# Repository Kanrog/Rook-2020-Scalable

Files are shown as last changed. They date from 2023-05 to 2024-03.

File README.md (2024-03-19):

<h1> Rook 2020 Scalable</h1>

<p>This is my mod for the Rook 2020 to make it fully scalable to any size.<br />
<h4>STLs are not updated here anymore, only on printables.</h4>
<h3><a href="https://www.printables.com/model/482283-rook-2020-scalable-mk1" rel="ugc" target="_blank">Check this out on printables </a></h3>
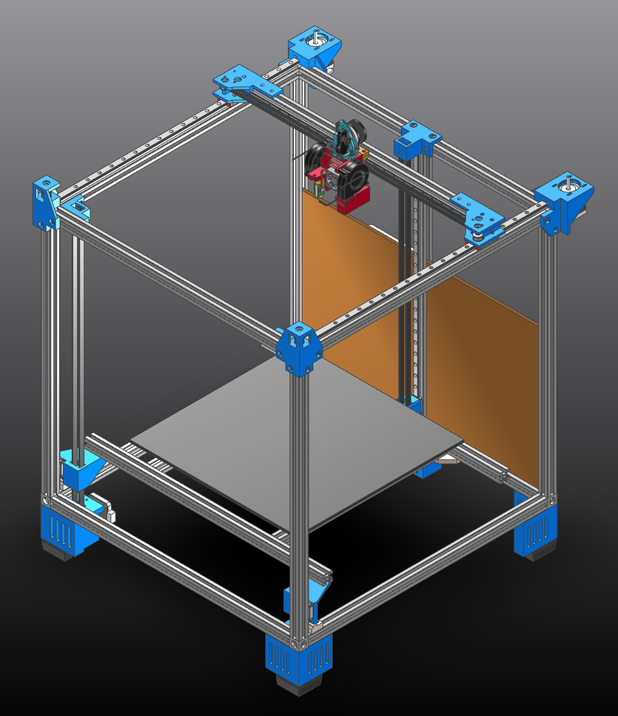
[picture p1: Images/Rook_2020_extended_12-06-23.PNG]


<p>This also adds a tripple belted Z-axis<br />
<br />
Uses the same BOM as the ROOK 2020, but with some additional hardware.<br />
<em>(Full BOM will be made when it is built and tested)</em></p>

(please note, the diagonal step is not updated, it was only made for the bed-section)

<p><br />
<em><strong>To determine your extrusion and rail lenghts, add 150mm to your bed-size and 100mm to your desired Z-height</strong></em><br />
<br />
For a 200x200x200 build volume, your extrusions would be 350x350 for top and bottom frame and 300 for Z.<br />
<br />
<em><strong>X-axis extrusion and rail is 50mm shorter than your top frame.</strong></em><br />
<br />
<p>Bed is made up of 2x extrusions the same length as your top frame and 2x the same as your top-frame - 150mm.<p/>
<br />
Supports MGN9C for the Z axis and X axis, and MGN12C for Y-axis.<br />
In theory, the X axis can use any rail to adapt to your desired printhead.<br />
<br />
Here is a calculator by Icesythe7 and MartinBspheroid to help you find your sizes!<br />

<h3><a href="https://kanrog.github.io/Rook-2020-Scalable-Calculator/" rel="ugc" target="_blank">Rook Scalable Calculator </a></h3>

<br />
Want to use the parts from your Ender-3? have a look at <a href="https://www.printables.com/model/487388-rook-e3" rel="ugc" target="_blank">THIS</a></p>

<a href="https://docs.google.com/spreadsheets/d/1HToAhn2cysvaPQEpnX_CcEi542RhAoKbjcgvA1xYTR8/edit?usp=sharing" rel="ugc" target="_blank">Rough BOM (WIP)</a></p>

<h4><br />
<em>Want to help me beta-test this? let me know!</em></h4>



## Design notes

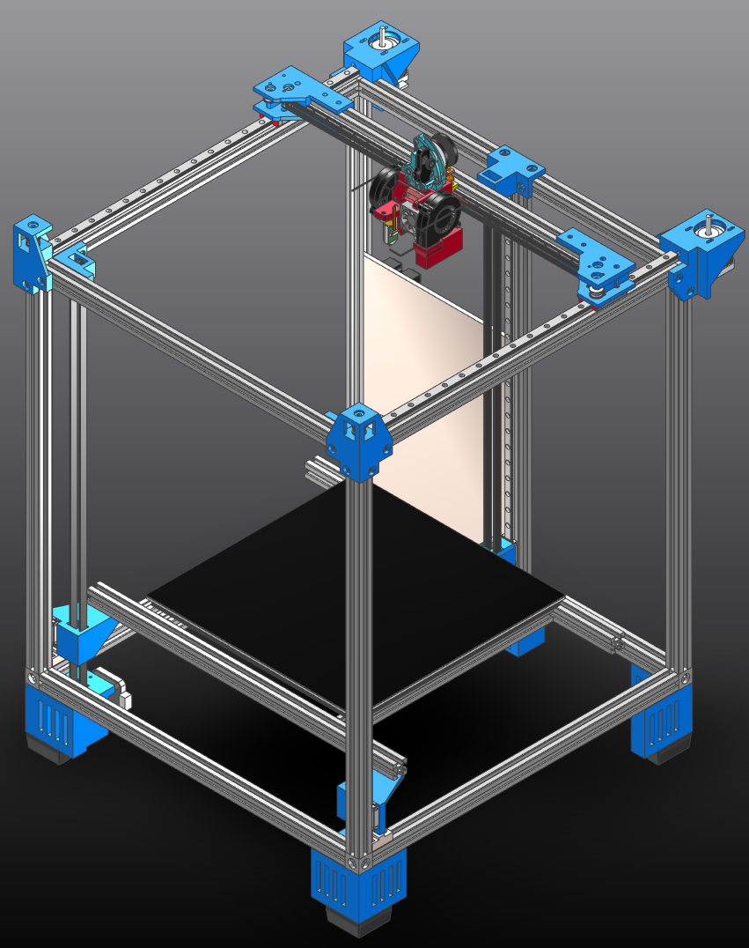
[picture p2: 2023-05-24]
Images/Rook_2020_extended.PNG

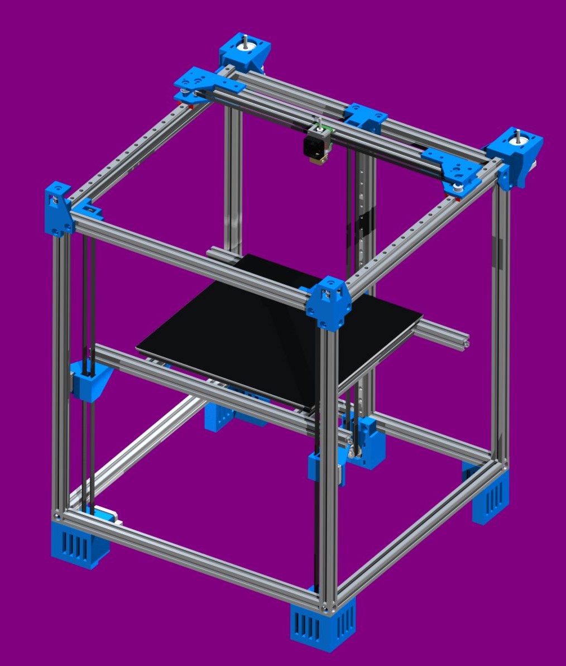
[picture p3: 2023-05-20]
Images/ICRender_crop.jpg

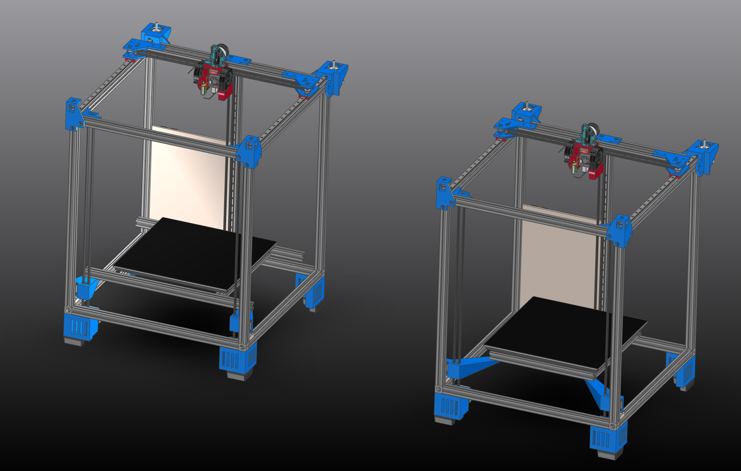
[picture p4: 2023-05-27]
Images/Rook_2020_extended_diagonal.PNG

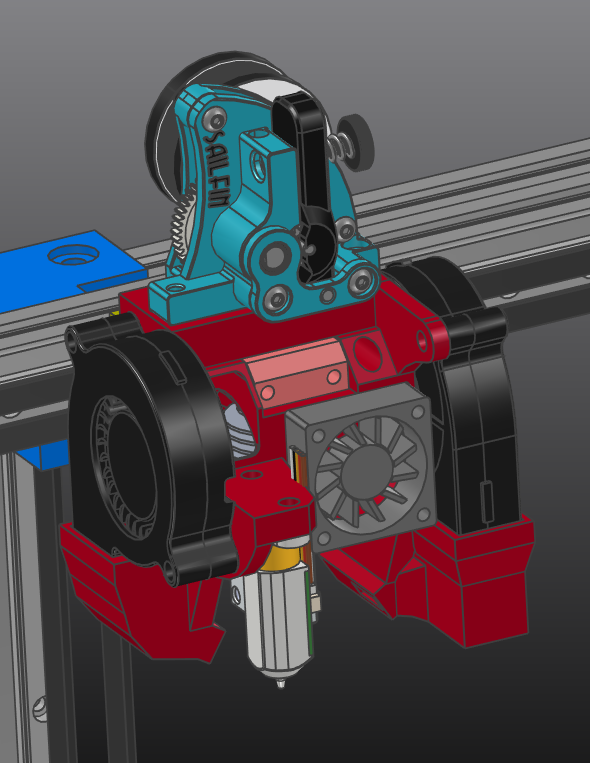
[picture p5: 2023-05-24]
Images/Brick_v0.PNG

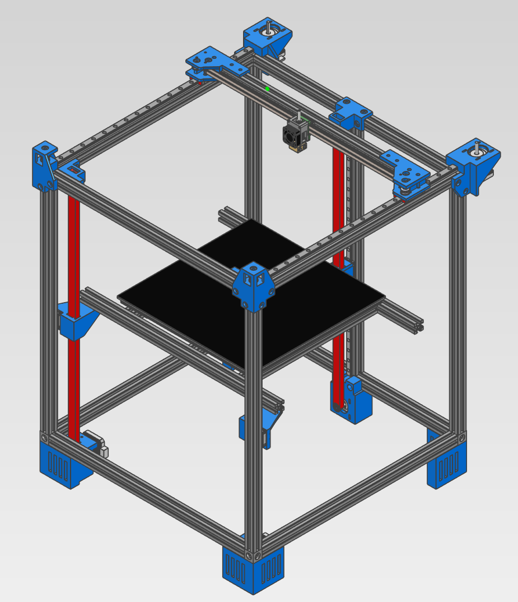
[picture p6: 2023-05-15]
Images/rook2020scalable.PNG

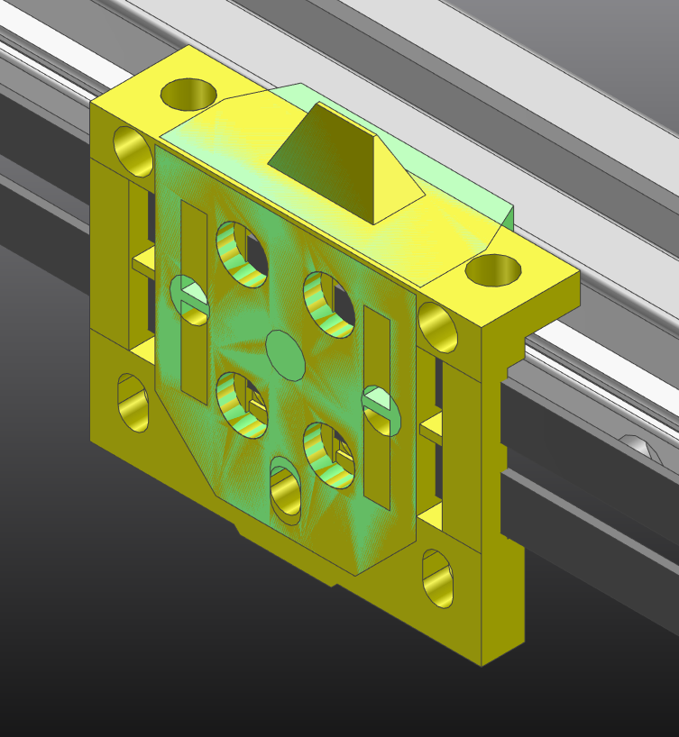
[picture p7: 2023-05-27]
Images/Brick_v0_plate_origin.PNG

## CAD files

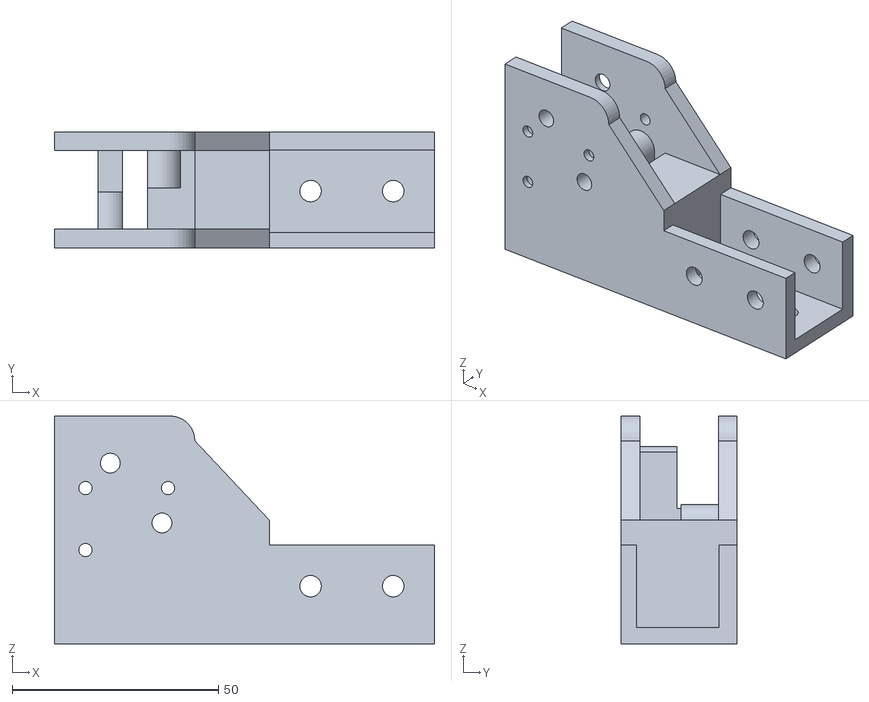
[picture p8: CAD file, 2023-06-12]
STL/1x_Y_Carriage Left_MGN12C.stl
92.0 x 28.1 x 55.2

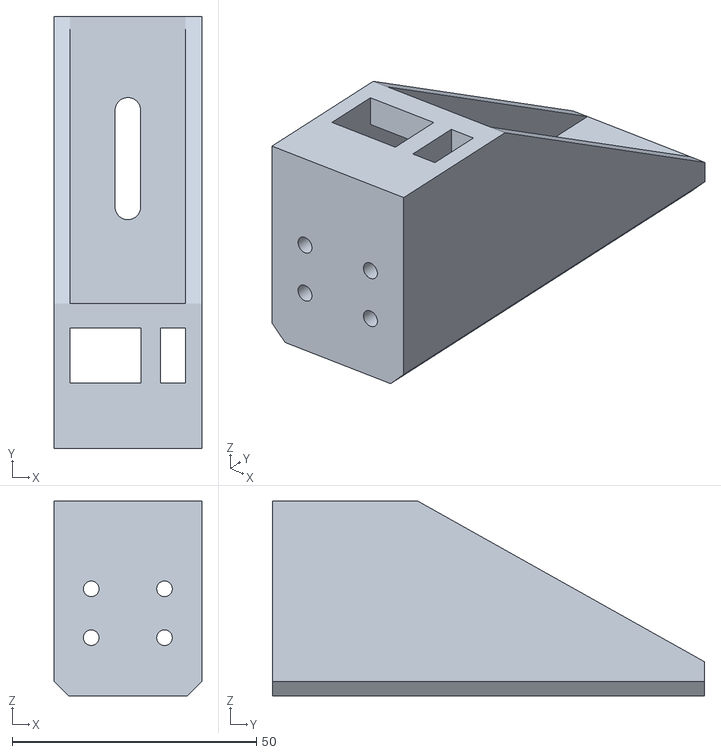
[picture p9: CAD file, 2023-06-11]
STL/1x_Z Carriage Rear_V2.stl
30.2 x 88.4 x 39.9

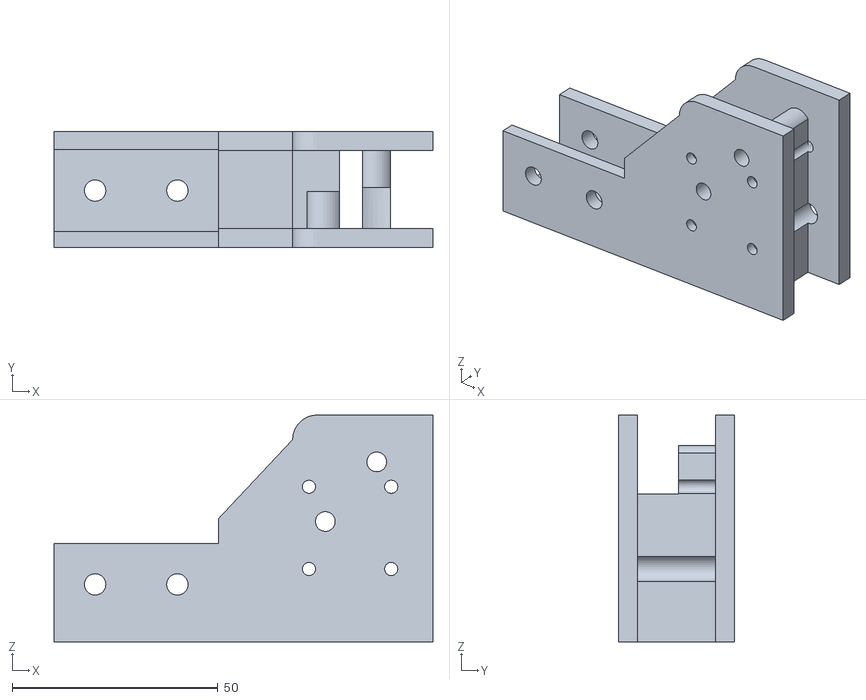
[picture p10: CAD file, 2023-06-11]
STL/1x_Y_Carriage Right_MGN12H.stl
92.2 x 28.1 x 55.2

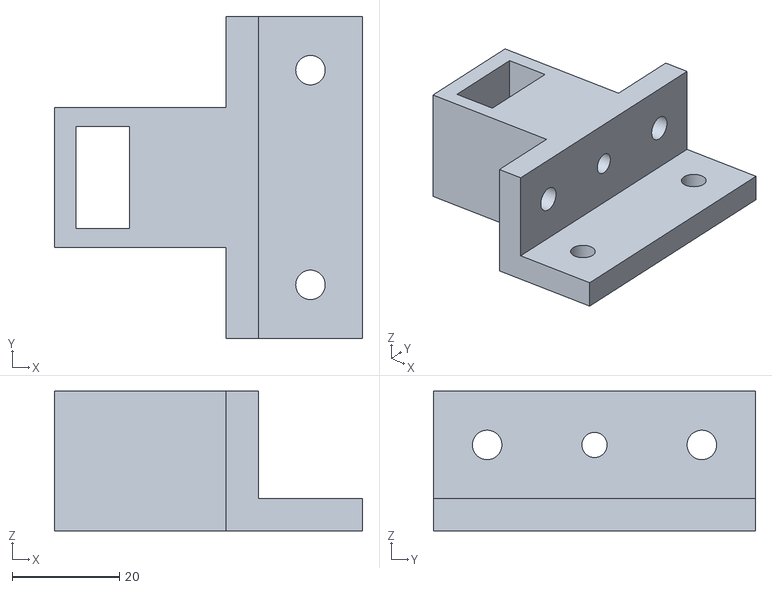
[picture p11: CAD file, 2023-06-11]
STL/1x_Z-Idler Rear.stl
57.4 x 60.0 x 26.0

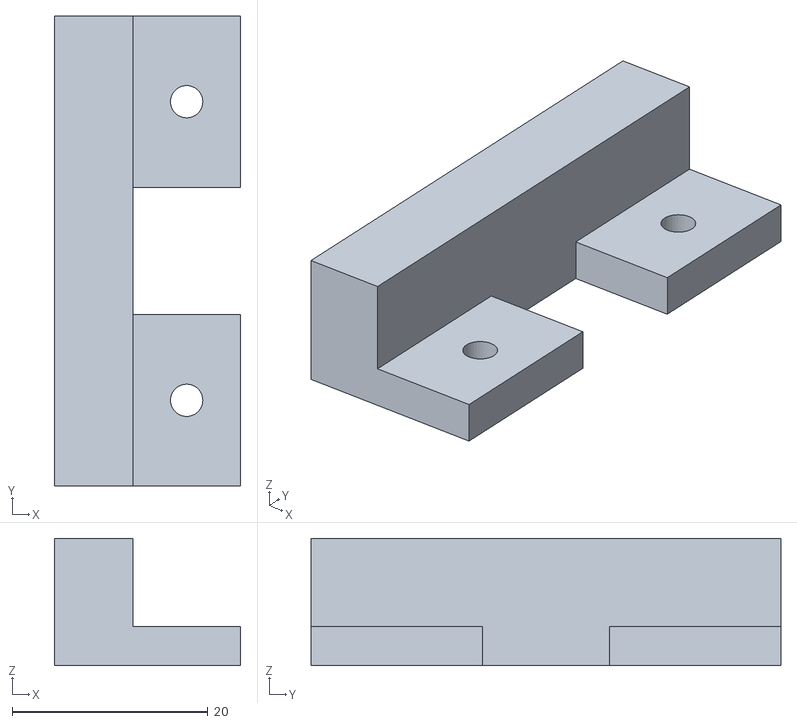
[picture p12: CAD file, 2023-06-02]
STL/1x_TPU-dampener rear.stl
19.0 x 48.0 x 13.0

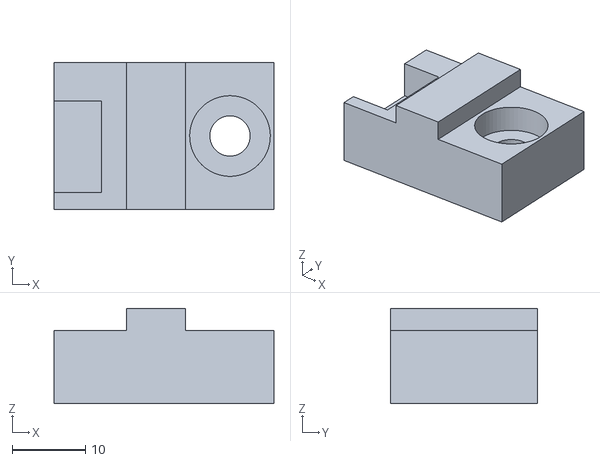
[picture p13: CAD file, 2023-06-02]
STL/2x_TPU-dampener front.stl
30.0 x 20.0 x 13.0

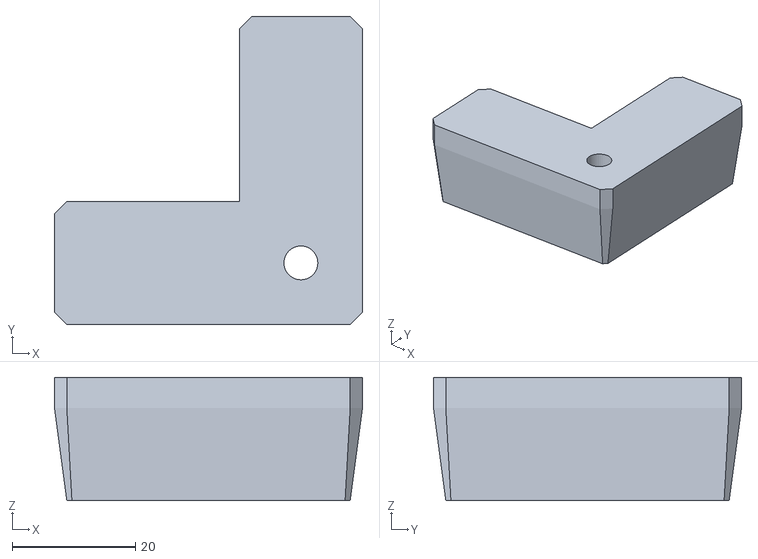
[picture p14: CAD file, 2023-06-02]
STL/4x_ TPU-feet.stl
50.0 x 50.0 x 20.0

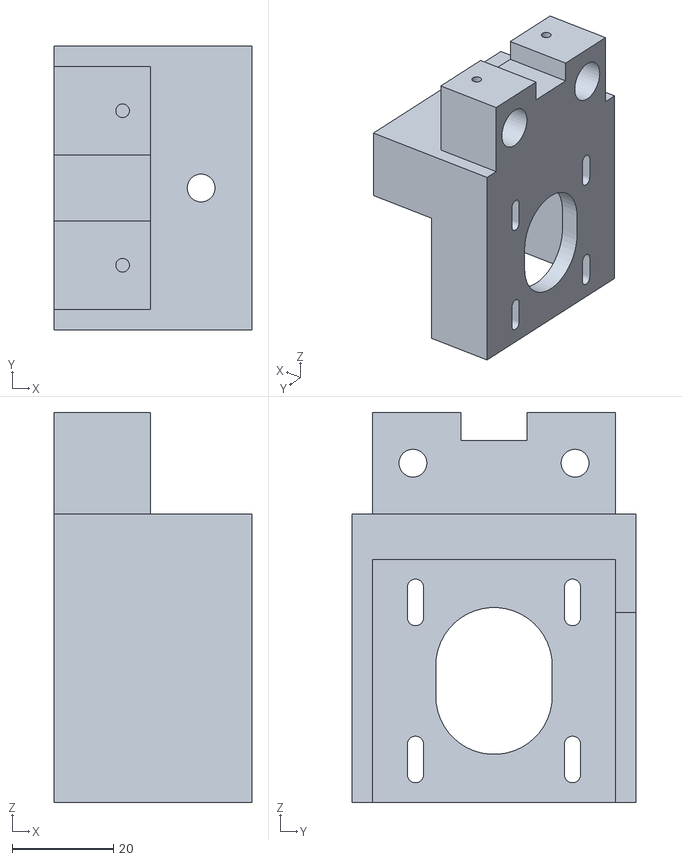
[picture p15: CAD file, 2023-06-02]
STL/1x_Z motor Rear.stl
39.0 x 56.0 x 77.0

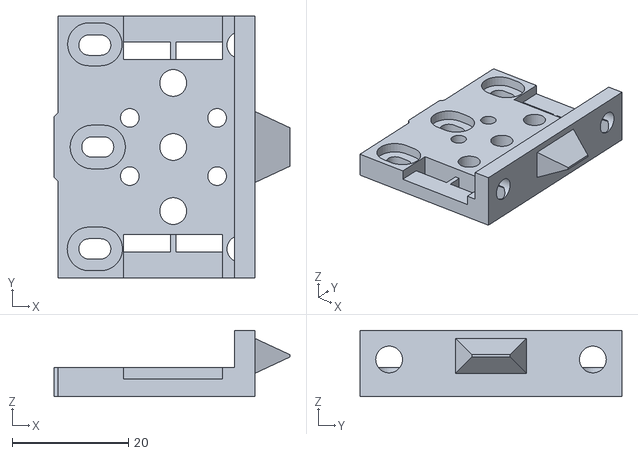
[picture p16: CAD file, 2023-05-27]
STL/Belt Base.stl
40.5 x 45.0 x 11.4

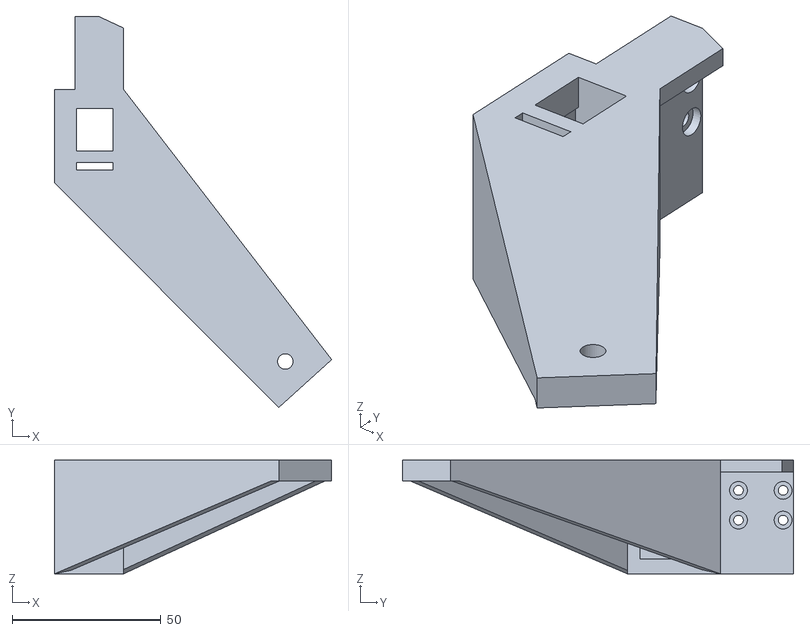
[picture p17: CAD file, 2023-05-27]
STL/1x_Z_Carriage_Left_Diagonal.stl
93.3 x 131.5 x 38.2

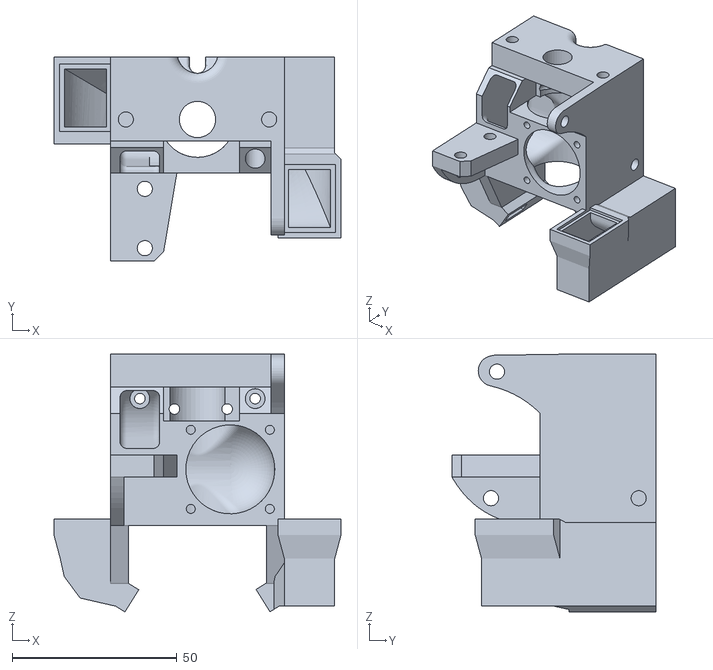
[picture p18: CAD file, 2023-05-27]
STL/Brick_V0.stl
87.1 x 62.0 x 78.3

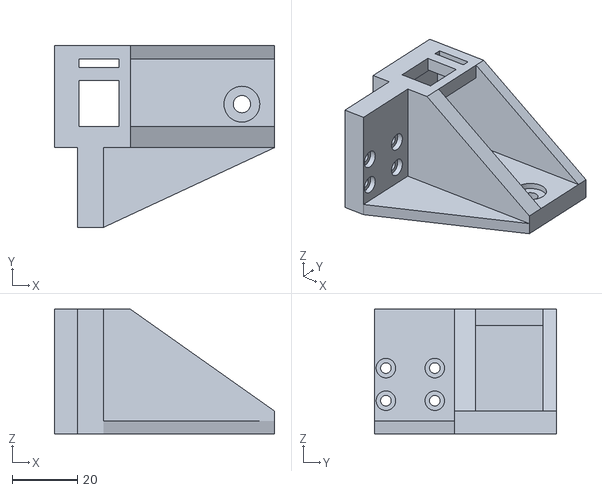
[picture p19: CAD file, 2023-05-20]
STL/1x_Z Carriage Left.stl
67.5 x 55.8 x 38.2

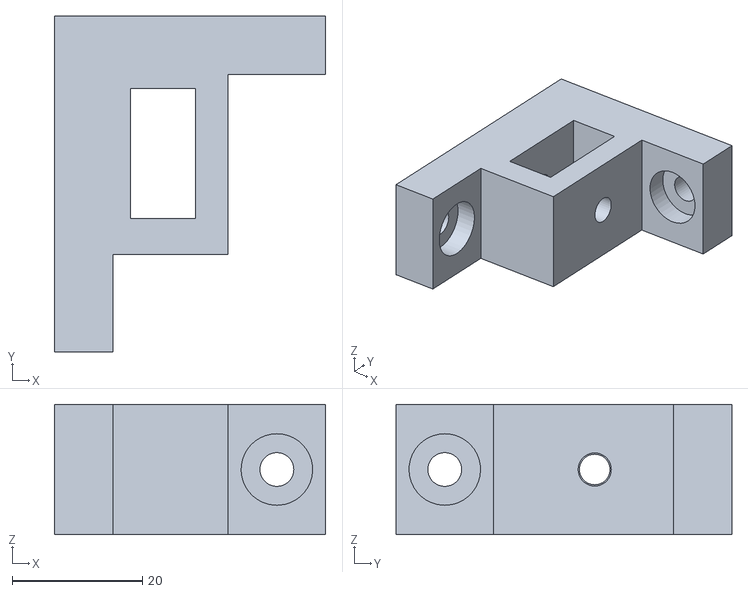
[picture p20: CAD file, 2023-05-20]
STL/2x_Z-Idler.stl
41.7 x 51.7 x 20.0

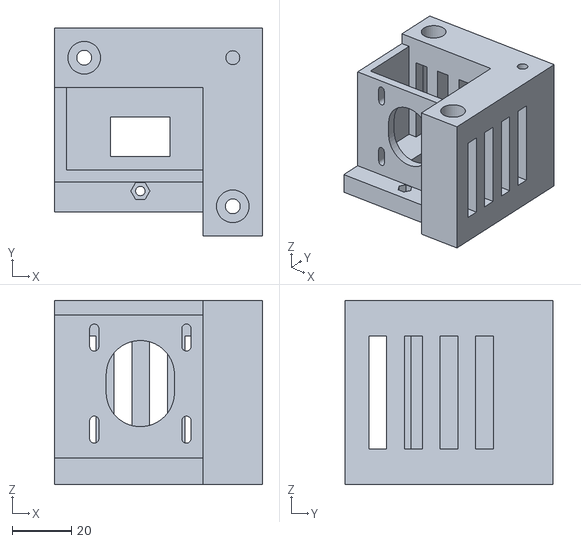
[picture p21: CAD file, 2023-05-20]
STL/1x_Z motor Right.stl
70.0 x 70.0 x 62.0

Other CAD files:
STL/1x_Y_Carriage Left_MGN12H.stl
STL/1x_Y_Carriage Right_MGN12C.stl
STL/1x_Z Carriage Right_Diagonal.stl
STL/1x_Z motor Left.stl
STL/1x_Motor Mount Left.stl
STL/1x_Motor Mount Right.stl
STL/1x_Z Carriage Rear.stl
STL/1x_Z Carriage Right.stl
STL/2x_Idler.stl
STL/2x_Rear Feet.stl
STL/4X_Bed-Mount.stl

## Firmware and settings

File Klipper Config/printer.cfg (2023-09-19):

#####################################################################
############## Said-Rook 2020 scalable designed by Kanrog ###########
#####################################################################

## *** THINGS TO CHANGE/CHECK: ***
## MCU paths                            [mcu] section
## Thermistor types                     [extruder] and [heater_bed] sections - See https://www.klipper3d.org/Config_Reference.html#common-thermistors for common thermistor types
## Leadscrew Rotation Distance          [stepper_z], [stepper_z1], [stepper_z2]
## Z Endstop Switch location            [safe_z_home] section
## Z Endstop Switch  offset for Z0      [stepper_z] section
## PID tune                             [extruder] and [heater_bed] sections
## Probe pin                            [probe] section
## Fine tune E steps                    [extruder] section
####################################################################
# Include Folders
####################################################################
[exclude_object]
[include mainsail.cfg]
#[include KAMP/*cfg]
[include sensorless_homing_macro.cfg]
[include macros.cfg]
#[include adaptive_mesh.cfg]
#[input_shaper]
#[include PIS.cfg]
#[include timelapse.cfg]

#####################################################################
# Printer
#####################################################################

[mcu]
serial: /dev/serial/by-id/usb-Klipper_stm32f407xx_310043000D50304B57383620-if00
restart_method: command

[printer]
kinematics: corexy
max_velocity: 500  
max_accel: 6000       
max_z_velocity: 100     #Max 15 for 12V TMC Drivers, can increase for 24V
max_z_accel: 200          
square_corner_velocity: 5

#[input_shaper]
#shaper_freq_x: 64.0
#shaper_type_x: mzv
#shaper_freq_y: 60.8
#shaper_type_y: mzv

#[safe_z_home]
#home_xy_position: 150, 150 # Change coordinates to the center of your print bed
#speed: 150
#z_hop: 0              # keep 0 , else bed will try to go down when homing
#z_hop_speed: 5
#####################################################################
#  Slicer 
#####################################################################

[gcode_arcs]
resolution: 0.1

[exclude_object]

#####################################################################
#               MISC
#####################################################################

[temperature_sensor Pi]
sensor_type: temperature_host
min_temp: 10
max_temp: 100

[temperature_sensor printer_temp]
sensor_type: temperature_mcu
min_temp: 0
max_temp: 100

[virtual_sdcard]
path: /home/pi/printer_data/gcodes
on_error_gcode: CANCEL_PRINT

#####################################################################
#   A/B Stepper Settings
#####################################################################

# Driver0 # Top Right
[stepper_x]
step_pin: PC14
dir_pin: !PC13
enable_pin: !PC15
microsteps: 64
rotation_distance: 40
full_steps_per_rotation: 200
endstop_pin: tmc2209_stepper_x:virtual_endstop
homing_retract_dist: 0
position_endstop: 350
position_max: 350
position_min: -50
homing_speed: 90

[tmc2209 stepper_x]
uart_pin: PE6
run_current: 1.1
sense_resistor: 0.110
#stealthchop_threshold: 999999
interpolate: False
diag_pin: PA14 # use the same pin that was previously the endstop_pin!
driver_SGTHRS: 120

# Driver1 Top Left
[stepper_y]
step_pin: PE5
dir_pin: !PE4
enable_pin: !PC15
microsteps: 64
rotation_distance: 40
full_steps_per_rotation: 200
endstop_pin: tmc2209_stepper_y:virtual_endstop
homing_retract_dist: 0
position_endstop: 350
position_max: 350
position_min: -50
homing_speed: 90

[tmc2209 stepper_y]
uart_pin: PE3
run_current: 1.1
sense_resistor: 0.110
#stealthchop_threshold: 999999
interpolate: False
diag_pin: PA15     # use the same pin that was previously the endstop_pin!
driver_SGTHRS: 120 # 255 is most sensitive value, 0 is least sensitive

#####################################################################
#   Z Stepper Settings
#####################################################################
##  Z-position of nozzle (in mm) to z-endstop trigger point relative to print surface (Z0)
##  (+) value = endstop above Z0, (-) value = endstop below

##  Driver3 front left
[stepper_z]
step_pin: PB5
dir_pin: !PB4
enable_pin: !PB6
rotation_distance:  40 #8 #Rotation Distance for TR8x8 = 8, TR8x4 = 4, TR8x2 = 2
full_steps_per_rotation: 200
microsteps: 16
endstop_pin: probe:z_virtual_endstop
homing_retract_dist: 10
#position_endstop: 0
position_max: 400
position_min: -5
homing_speed: 60 # Leadscrews are slower than 2.4, 10 is a recommended max.
second_homing_speed: 3
homing_retract_dist: 10
#homing_positive_dir: false

[tmc2209 stepper_z]
uart_pin: PB3
interpolate: False
run_current: 0.85 #0.40
sense_resistor: 0.110
stealthchop_threshold: 999999

##  Driver4 - Bottom Center ## 
[stepper_z1]
step_pin: PD6
dir_pin: !PD5
enable_pin: !PD7
rotation_distance: 40 #8  # Rotation Distance for TR8x8 = 8, TR8x4 = 4, TR8x2 = 2
full_steps_per_rotation: 200
microsteps: 16

[tmc2209 stepper_z1]
uart_pin: PD4
interpolate: False
run_current: 0.85 #0.40
sense_resistor: 0.110
stealthchop_threshold: 999999

##  Driver5 front right
[stepper_z2]
step_pin: PD2
dir_pin: !PD1
enable_pin: !PD3
rotation_distance:  40 #8  # Rotation Distance for TR8x8 = 8, TR8x4 = 4, TR8x2 = 2
full_steps_per_rotation: 200
microsteps: 16

[tmc2209 stepper_z2]
uart_pin: PD0
interpolate: False
run_current: 0.85 #0.40
sense_resistor: 0.110
stealthchop_threshold: 999999

#####################################################################
#   LDO Orbiter 2.0 Extruder 1.75mm
#####################################################################

# Driver6
[extruder]
step_pin: PC7 #PF11
dir_pin: !PC6
enable_pin: !PC8 #PG5
microsteps: 16
rotation_distance: 4.637
full_steps_per_rotation: 200
#gear_ratio: 7.5:1
nozzle_diameter: 0.400
filament_diameter: 1.750
heater_pin: PB0 # HE1
sensor_pin:  PC1 # T0
sensor_type: Generic 3950
min_temp: -200
max_temp: 300
max_extrude_cross_section:2
max_extrude_only_distance: 500
min_extrude_temp: 0
max_extrude_only_velocity: 120 
pressure_advance: 0.025
pressure_advance_smooth_time: 0.03  

[tmc2209 extruder]
uart_pin: PD15
run_current: 0.5
hold_current: 0.100 
stealthchop_threshold: 0 
driver_TBL: 0 
driver_HEND: 6 
driver_HSTRT: 7 
driver_TOFF: 4 
sense_resistor: 0.110
interpolate: True

#####################################################################
#   Bed Heater
#####################################################################

[heater_bed]
heater_pin: PB10
sensor_pin: PC0
sensor_type: EPCOS 100K B57560G104F
min_temp: -200
max_temp: 130
pwm_cycle_time: 0.02
#control: watermark

#####################################################################
#   Fan Control
#####################################################################
#  * EXTRUDER  *

[heater_fan hotend_fan]
pin: PA2
max_power: 1.0
#kick_start_time: 0.5
heater: extruder
heater_temp: 50.0
##  If you are experiencing back flow, you can reduce fan_speed
fan_speed: 1

#[fan_generic extruder_partfan]
#pin: PD15
#max_power: 1.0

[controller_fan controller_fan]
pin: PA0
kick_start_time: 0.5
#heater: heater_bed
max_power: 1.0
#[heater_fan exhaust_fan]
##  Exhaust fan - FAN3
#pin: PD13
#max_power: 1.0
#shutdown_speed: 0.0
#kick_start_time: 5.0
#heater: heater_bed
#heater_temp: 60
fan_speed: 1.0

[fan]
##  Print Cooling Fan - FAN0
pin: PA1
kick_start_time: 1
##  Depending on your fan, you may need to increase this value
##  if your fan will not start. Can change cycle_time (increase)
##  if your fan is not able to slow down effectively
off_below: 0.10

#####################################################################
#   Probe
#####################################################################
[bltouch]
sensor_pin: PC3
control_pin: PA8
pin_move_time: 0.3
stow_on_each_sample: false
probe_with_touch_mode: false
pin_up_touch_mode_reports_triggered: true
x_offset: -15
y_offset: -32
#z_offset: 0
samples: 1
sample_retract_dist: 5
samples_result: average

[bed_mesh]
speed: 200
mesh_min: 40,40
mesh_max: 260,260
probe_count: 5
algorithm: bicubic
fade_start: 0
fade_end: 15
fade_target: 0

#####################################################################
#   Homing and Gantry Adjustment Routines
#####################################################################

[idle_timeout]
timeout: 1800

#[safe_z_home]
#home_xy_position:273.5,199
#speed: 50
#z_hop: 10


[z_tilt]
##  Use Z_TILT_ADJUST to level the bed
z_positions:
    -80, -30 #48, 1
    165, 335 #271.5, 0
    370, -30 #156.5, 220
points:
    20, 40 #48, 1
    165, 320 #271.5, 0
    305, 40 #156.5, 220
speed: 400
horizontal_move_z: 10
retries: 10
retry_tolerance: 0.05

#####################################################################
#   Filament Runout Senosr
#####################################################################

#[filament_switch_sensor]
#switch_pin: PG12

########################################
# EXP1 / EXP2 (display) pins
########################################
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

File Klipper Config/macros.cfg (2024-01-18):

#[save_variables]
#filename: ~/klipper_config/variables.cfg ; variable storage file
################################
######### START G-CODE #########
################################

[gcode_macro START_PRINT]
gcode:
    {% set T_BED = params.T_BED|default(50) %}
    {% set T_EXTRUDER = params.T_EXTRUDER|default(205) %}
    # Use absolute coordinates
    G92
    # Start bed heating and continue
    M140 S{T_BED}
    {% if printer.heater_bed.temperature > params.T_BED|float*0.85 %}
        M140 S{T_BED}
        M109 S{T_EXTRUDER} 
        M190 S{T_BED}
    {% else %}
        M190 S{params.T_BED|float*0.85} # wait till 0.85 of bed temp is reached, then continue
        M140 S{T_BED} 
        M109 S{T_EXTRUDER}
        M190 S{T_BED}
    {% endif %}

    #BUILD MESH
    G28
    Z_TILT_ADJUST
    BED_MESH_CALIBRATE
    BED_MESH_PROFILE LOAD=default

    # Prime line
    PRIME_LINE

##
##  For this macro to work, please add this to your slicer's start g-code
##
##  M190 S[bed_temperature_initial_layer_single]
##  M109 S[nozzle_temperature_initial_layer]
##  START_PRINT T_EXTRUDER=[nozzle_temperature_initial_layer] T_BED=[bed_temperature_initial_layer_single]
##
## (PLEASE remove the "##")
##
##

[gcode_macro END_PRINT]
gcode:
    G91 ; Relative positioning
    G1 E-15 F1800 ; Retract
    G90 ; Absolute pos.
    G1 X20 Y20 F5000
    # Turn off bed, extruder, and fan
    M140 S0
    M104 S0
    M106 S0
    BED_PARK
    M84 ; Disable steppers
##
##  For this macro to work, please add this to your slicer's start g-code
##  
##  END_PRINT
##
## (PLEASE remove the "##")
##
##

# prime the nozzle 
[gcode_macro PRIME_LINE]
gcode: 
    M117 Prime Line
    G92 E0 ;Reset Extruder
    # move z axis 
    G1 Z2.0 F3000 ;Move Z Axis up
    # move to prime position 
    G1 X2.1 Y20.0 Z0.28 F5000.0 ;Move to start position
    G1 X2.1 Y150.0 Z0.28 F1500.0 E15 ;Draw the first line
    G1 X2.4 Y150.0 Z0.28 F5000.0 ;Move to side a little
    G1 X2.4 Y20.0 Z0.28 F1500.0 E30 ;Draw the second line
    G92 E0 ;Reset Extruder
    G1 Z2.0 F3000 ;Move Z Axis up

[gcode_macro BED_MESH]
gcode:
    G28
    BED_MESH_CALIBRATE
    G0 X1 Y1 Z10 F6000
    BED_MESH_PROFILE save=default

#=====================================================
# Filament IN
#=====================================================
[gcode_macro FILAMENT_IN]
description: Filament In
gcode:
  G91
  G1 E60 F2000
  G1 E50 F600
  G1 E-5 F400
  G90

#=====================================================
# Filament OUT
#=====================================================
[gcode_macro FILAMENT_OUT]
description: Filament Out
gcode:
  G91
  G1 E10 F600
  G1 E-100 F2000
  G90

#=====================================================
# Torture XY Small
#=====================================================
[gcode_macro TORTURE_XY_SMALL]
description: Test x and y axis movements
gcode:
  {% if "xyz" not in printer.toolhead.homed_axes %}
  G28
  {% endif %}
  G90
  G1 X100 Y100 F10000
  G1 Z10 F5000
  G91
    {% set repeat_count = 8 %}
  {% for repeat in range(repeat_count) %}
  G1 X+100 F500000
  G1 Y+100 F500000
  G1 X-100 F500000
  G1 Y-100 F500000
  {% endfor %}
  G90

#=====================================================
# Torture XY Big
#=====================================================
[gcode_macro TORTURE_XY_BIG]
description: Test x and y axis movements
gcode:
  {% if "xyz" not in printer.toolhead.homed_axes %}
  G28
  {% endif %}
  G90
  G1 X50 Y50 F10000
  G1 Z10 F5000
  G91
    {% set repeat_count = 8 %}
  {% for repeat in range(repeat_count) %}
  G1 X+200 F500000
  G1 Y+200 F500000
  G1 X-200 F500000
  G1 Y-200 F500000
  {% endfor %}
  G90

#=====================================================
# XY Shake
#=====================================================
[gcode_macro TORTURE_SHAKE]
description: Test x and y axis movements
gcode:
  {% if "xyz" not in printer.toolhead.homed_axes %}
  G28
  {% endif %}
  G90
  G1 X150 Y150 F10000
  G1 Z10 F5000
  G91
    {% set repeat_count = 10 %}
  {% for repeat in range(repeat_count) %}
  G1 X+15 F500000
  G1 X-15 F500000
  {% endfor %}
  G90
  G91
    {% set repeat_count = 10 %}
  {% for repeat in range(repeat_count) %}
  G1 Y+15 F500000
  G1 Y-15 F500000
  {% endfor %}
  G90

#=====================================================
# Torture XY Big
#=====================================================
[gcode_macro TORTURE_Z]
description: Test x and y axis movements
gcode:
  {% if "xyz" not in printer.toolhead.homed_axes %}
  G28
  {% endif %}
  G90
  G1 X150 Y150 F10000
  G1 Z10 F5000
  G91
    {% set repeat_count = 8 %}
  {% for repeat in range(repeat_count) %}
  G1 Z+370 F500000
  G1 Z-370 F500000
  {% endfor %}
  G90

#=====================================================
# Park Bed
#=====================================================
[gcode_macro BED_PARK]
description: Send bed to bottom
gcode:
  G90
  G1 Z390 F10000
  G90

#=====================================================
# Walk
#=====================================================
[gcode_macro WALK]
description: RUN FORREST! RUN!!
gcode:
    {% if "xyz" not in printer.toolhead.homed_axes %}
  G28
  {% endif %}
  G90
  G1 X5 Y5 F10000
  G1 Z30 F5000
  G91
    {% set repeat_count =20 %}
  {% for repeat in range(repeat_count) %}
  G1 Y+250 F500000
  G1 Y-250 F500000
  {% endfor %}
  G90

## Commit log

2023-05-20 STL upload
    [1x_Motor Mount Left.stl, 1x_Motor Mount Right.stl, 1x_Y-Carriage Right.stl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]
2023-05-20 Update 1x_Z Carriage Rear.stl
    [1x_Z Carriage Rear.stl]
2023-05-23 added BOM and update stp
2023-05-27 added diagonal
    [1x_Z Carriage Rear_V2.stl, 1x_Z Carriage Right_Diagonal.stl, 1x_Z_Carriage_Left_Diagonal.stl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]
2023-06-11 Update 1x_Y-Carriage Right.stl
    [1x_Y-Carriage Right.stl]
2023-06-11 Y-fix +++
    [1x_Y-Carriage Right.stl, 1x_Y_Carriage Left.stl, 1x_Y_Carriage Left_MGN12C.stl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]
2023-06-11 Update 1x_Z Carriage Rear_V2.stl
    [1x_Z Carriage Rear_V2.stl]
2023-06-12 Update 1x_Y_Carriage Left_MGN12C.stl
    [1x_Y_Carriage Left_MGN12C.stl]
2023-09-19 added configs
    [macros.cfg, printer.cfg, sensorless_homing_macro.cfg]
2024-01-18 Update macros.cfg
    add start/end gcode examples
    [macros.cfg]
